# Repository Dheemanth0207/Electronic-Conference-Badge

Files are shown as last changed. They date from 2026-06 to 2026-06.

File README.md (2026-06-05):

# Electronic Conference Badge

## Project Overview

This project investigates the design and development of a smart, energy-efficient electronic conference badge intended to replace traditional printed name tags used at events and meetings. The system is built around a compact microcontroller board, which controls a 3.52-inch e-paper display capable of showing attendee names, designations, or other event-specific content. Unlike conventional displays, e-paper offers excellent readability in various lighting conditions, including bright sunlight, while consuming very little power, making it ideal for multi-day usage on a single charge. 

The badge is designed to be interactive and easily programmable, featuring a set of physical buttons for input and wireless communication that allow it to connect with other badges or systems for capabilities such as contact exchange, activity tracking, or peer-to-peer messaging. A SD card reader also provides the flexibility to update the badge content without relying on an internet connection, making it useful in both connected and standalone scenarios

To reliably support all of these features, the hardware integrates a combination of power management circuits to ensure stable operation across different use cases. These include a voltage regulator and boost converter to provide the necessary voltages for the logic components and display. The board is powered by a 3.7V rechargeable battery and is charged or programmed via a USB Type-C connector. 

All design work, including schematic creation and PCB layout, was completed using the open-source KiCAD 9 design tool, ensuring that the board is optimized for surface-mount manufacturing. By combining low-power electronics, open-source design tools, and a thoughtful user interface, this badge system offers a modern, reusable, and sustainable alternative to traditional paper-based identification at events. 

## Hardware Preview

### Schematic
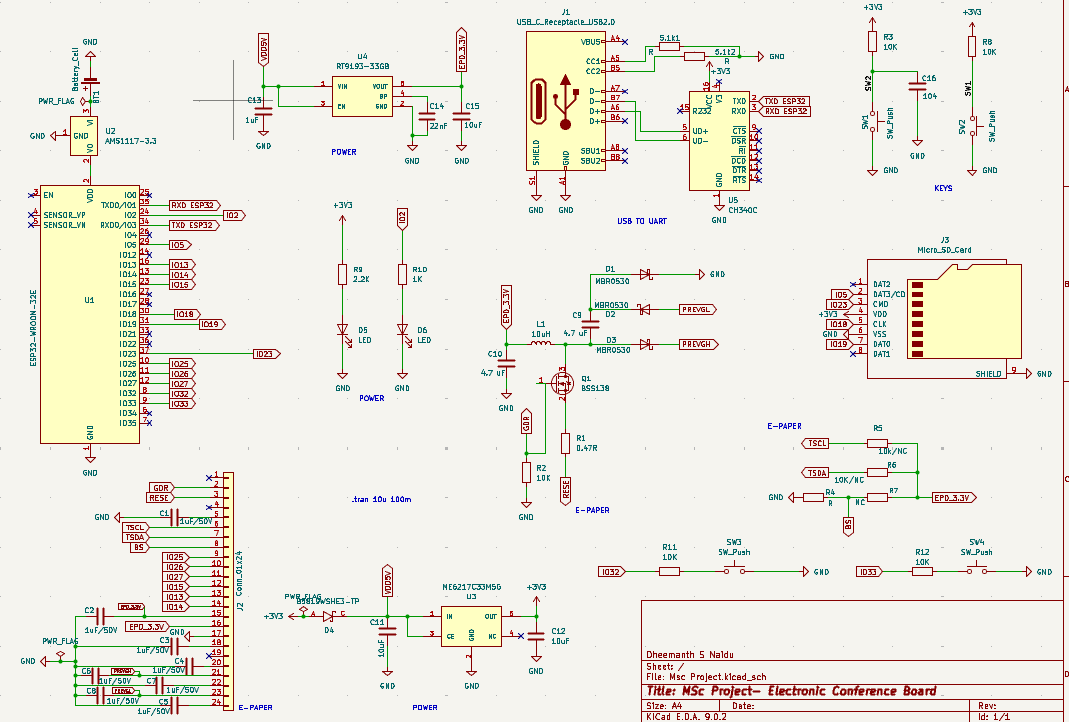
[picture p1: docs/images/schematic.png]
Schematic


### PCB Layout
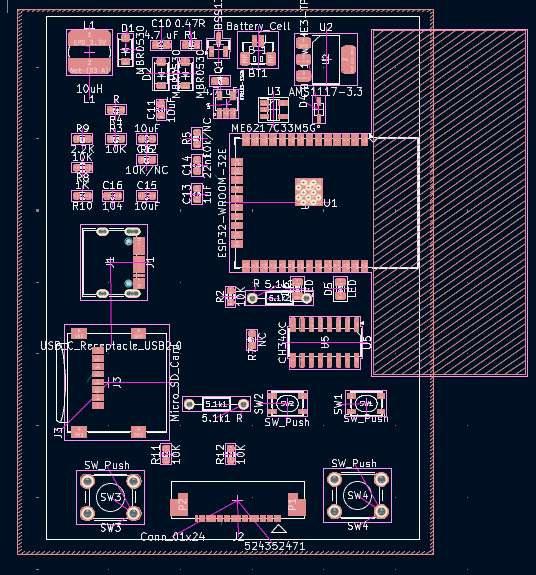
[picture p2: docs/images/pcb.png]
PCB Layout


### 3D Render
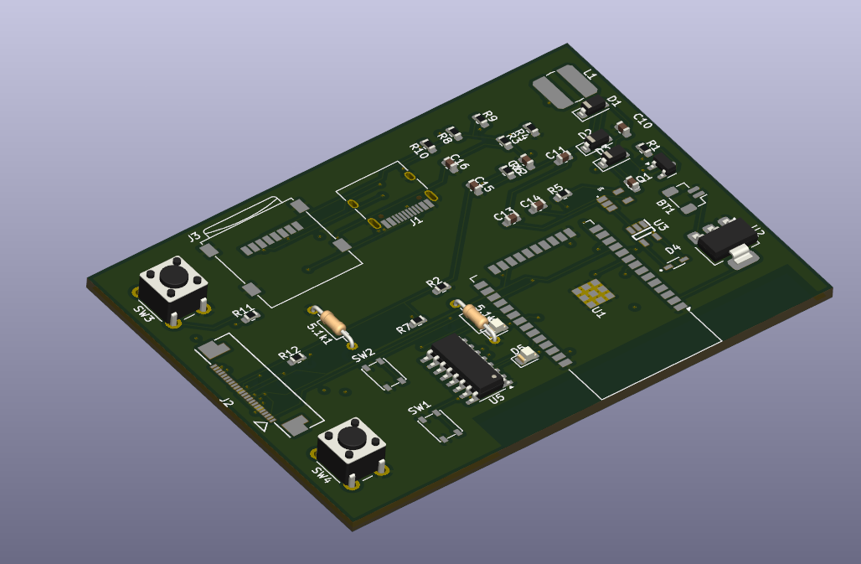
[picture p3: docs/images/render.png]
3D Render


## 🛠️ Requirements

To view, edit, or manufacture this project, the following software is required:

* **KiCad 9.0 or later**
* A computer running Windows, Linux, or macOS
* Optional: Gerber viewer for manufacturing file verification

## 📥 Installation

### 1. Install KiCad

Download and install the latest version of KiCad from the official website:

https://www.kicad.org/download/

Verify that KiCad is correctly installed by launching the application and opening the Project Manager.

### 2. Clone the Repository

```bash
git clone https://github.com/<your-username>/<repository-name>.git
cd <repository-name>
```

Alternatively, download the project as a ZIP file and extract it to your desired location.

### 3. Open the Project

1. Launch **KiCad 9**.
2. Select **File → Open Project**.
3. Navigate to the project directory.
4. Open the `.kicad_pro` file.

The project schematic, PCB layout, symbols, footprints, and manufacturing files will now be available through the KiCad Project Manager.

## 📂 Project Structure

```text
Project/
│
├── Hardware/
│   ├── Schematics/
│   ├── PCB/
│   ├── Libraries/
│   └── Manufacturing/
│
├── Documentation/
│   ├── Images/
│   └── Datasheets/
│
└── README.md
```

## 🔧 Editing the Design

### Schematic

1. Open the project in KiCad.
2. Click **Schematic Editor**.
3. Modify components, connections, or annotations as required.
4. Run **Electrical Rules Check (ERC)** before saving changes.

### PCB Layout

1. Open **PCB Editor**.
2. Update the PCB from the schematic if changes have been made.
3. Verify component placement and routing.
4. Run **Design Rules Check (DRC)** to identify any layout issues.

## 📤 Generating Manufacturing Files

To generate fabrication files:

1. Open the PCB Editor.
2. Select **File → Fabrication Outputs → Gerbers**.
3. Generate Gerber files for all required layers.
4. Generate drill files using **Generate Drill Files**.
5. Review the outputs using a Gerber viewer before sending them to a PCB manufacturer.

## 🔋 Hardware Features

* 3.52-inch E-Paper Display
* Low-power microcontroller platform
* Wireless communication capability
* Physical navigation buttons
* MicroSD card support
* USB Type-C charging and programming
* Rechargeable 3.7 V Li-ion battery support
* Integrated voltage regulation and boost conversion circuitry
* Surface-mount optimized PCB design

## 🤝 Contributing

Contributions, suggestions, and improvements are welcome. Please fork the repository, create a feature branch, and submit a pull request describing your changes.

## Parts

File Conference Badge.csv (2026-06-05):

Id | Designator | Footprint | Quantity | Designation | Supplier and ref
1 | R7 | R_0603_1608Metric | 1 | NC
2 | 5.1k1,5.1k2 | R_Axial_DIN0204_L3.6mm_D1.6mm_P7.62mm_Horizontal | 2 | R
3 | R11,R8,R2,R12,R3 | R_0603_1608Metric | 5 | 10K
4 | C8,C1,C2,C3,C4,C7,C5,C6 | C_0603_1608Metric | 8 | 1uF/50V
5 | C12,C11,C15 | C_0603_1608Metric | 3 | 10uF
6 | D2,D3,D1 | D_SOD-123 | 3 | MBR0530
7 | R4 | R_0603_1608Metric | 1 | R
8 | C14 | C_0603_1608Metric | 1 | 22nF
9 | R10 | R_0603_1608Metric | 1 | 1K
10 | J3 | microSD_HC_Wuerth_693072010801 | 1 | Micro_SD_Card
11 | SW3,SW4 | SW_PUSH_6mm | 2 | SW_Push
12 | L1 | L_Bourns_SDR0604 | 1 | 10uH
13 | BT1 | JST_SH_BM02B-SRSS-TB_1x02-1MP_P1.00mm_Vertical | 1 | Battery_Cell
14 | C16 | C_0603_1608Metric | 1 | 104
15 | C10,C9 | C_0603_1608Metric | 2 | 4.7 uF
16 | J2 | CON_524352471_MOL | 1 | Conn_01x24
17 | Q1 | SOT-23 | 1 | BSS138
18 | U4 | SOT94P279X129-5N | 1 | RT9193-33GB
19 | R1 | R_0603_1608Metric | 1 | 0.47R
20 | D5,D6 | LED_0805_2012Metric | 2 | LED
21 | C13 | C_0603_1608Metric | 1 | 1uF
22 | U2 | SOT-223-3_TabPin2 | 1 | AMS1117-3.3
23 | D4 | SOD2512X115N | 1 | B5819WSHE3-TP
24 | U3 | SOT23-5 | 1 | ME6217C33M5G
25 | J1 | USB_C_Receptacle_HRO_TYPE-C-31-M-12 | 1 | USB_C_Receptacle_USB2.0
26 | SW2,SW1 | SW_SPST_PTS810 | 2 | SW_Push
27 | R6 | R_0603_1608Metric | 1 | 10K/NC
28 | U5 | SOIC-16_3.9x9.9mm_P1.27mm | 1 | CH340C
29 | R5 | R_0603_1608Metric | 1 | 10k/NC
30 | U1 | ESP32-WROOM-32D | 1 | ESP32-WROOM-32E
31 | R9 | R_0603_1608Metric | 1 | 2.2K

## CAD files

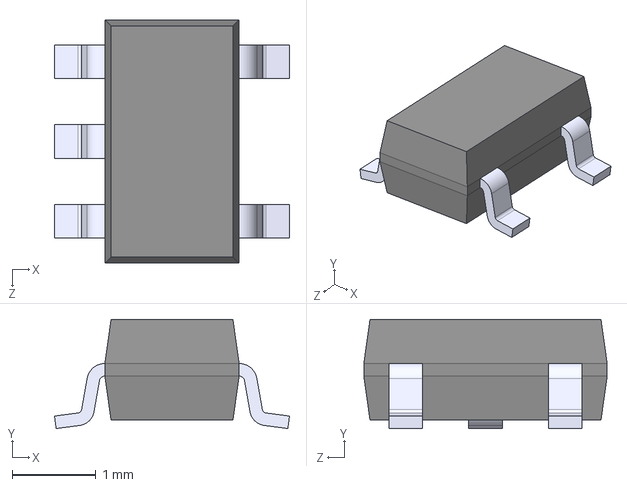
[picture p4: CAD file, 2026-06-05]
ME6217C33M5G/ME6217C33M5G.step
2.80 x 1.30 x 2.90 mm

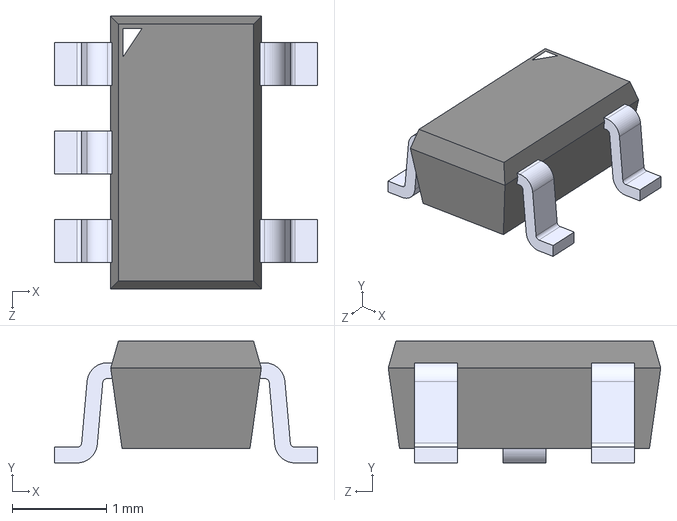
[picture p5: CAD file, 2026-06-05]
RT9193-33GB/RT9193-33GB.step
2.79 x 1.30 x 2.90 mm

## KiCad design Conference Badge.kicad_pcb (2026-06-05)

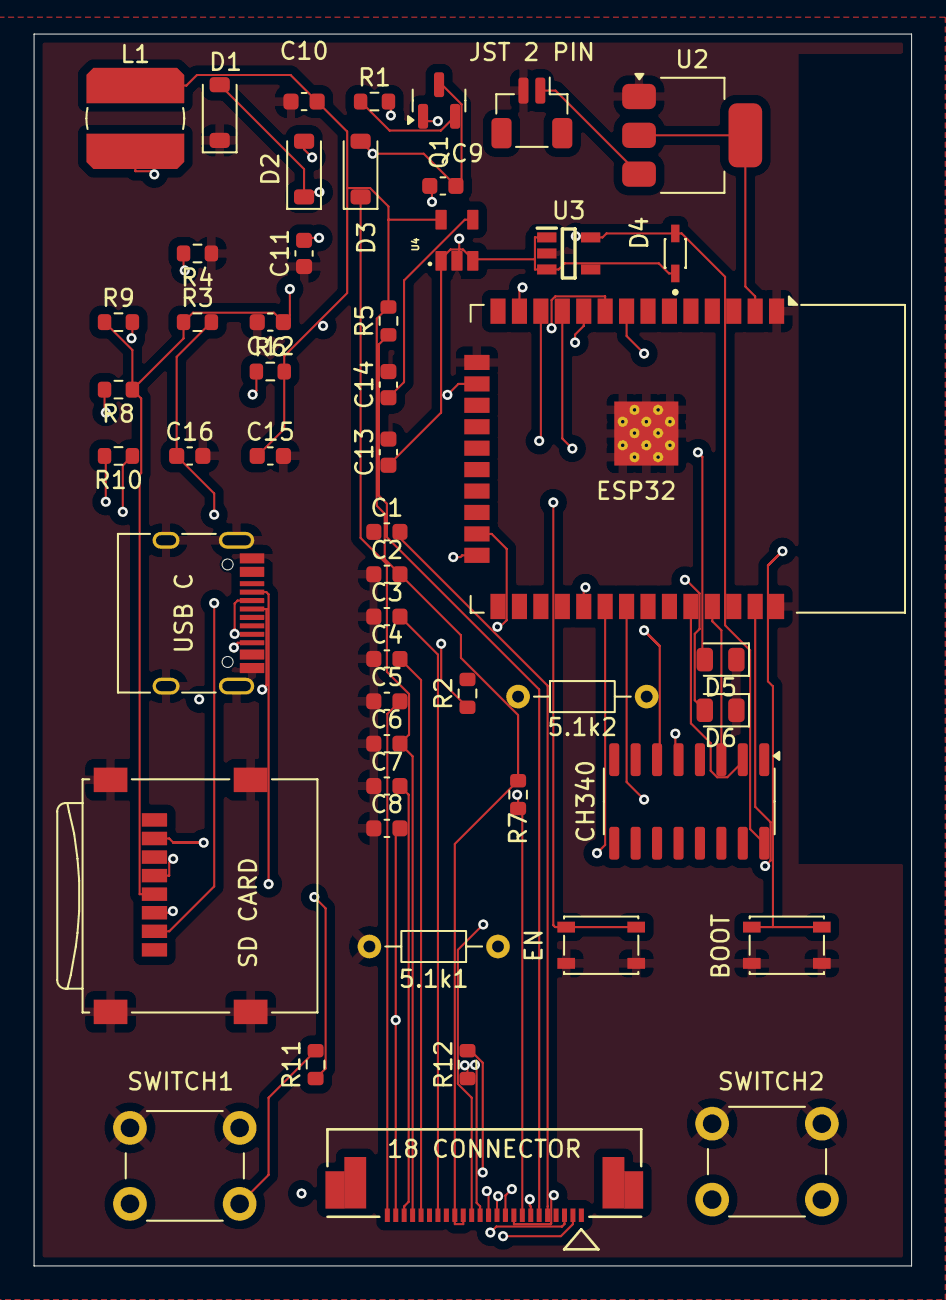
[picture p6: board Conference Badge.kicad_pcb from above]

Board: 4 copper layers, 52.0 x 73.0 mm, 51 parts (0 on the bottom side), 47 nets.

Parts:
5.1k1, 5.1k2: R; R_Axial_DIN0204_L3.6mm_D1.6mm_P7.62mm_Horizontal
18 CONNECTOR : Conn_01x24; CON_524352471_MOL
BOOT: BOOT; SW_SPST_PTS810
C1, C2, C3, C4, C5, C6, C7, C8: 1uF/50V; C_0603_1608Metric
C9, C10: 4.7 uF; C_0603_1608Metric
C11, C12, C15: 10uF; C_0603_1608Metric
C13: 1uF; C_0603_1608Metric
C14: 22nF; C_0603_1608Metric
C16: 104; C_0603_1608Metric
CH340: CH340C; SOIC-16_3.9x9.9mm_P1.27mm
D1, D2, D3: MBR0530; D_SOD-123
D4: B5819WSHE3-TP; SOD2512X115N
D5, D6: LED; LED_0805_2012Metric
EN: EN; SW_SPST_PTS810
ESP32: ESP32-WROOM-32E; ESP32-WROOM-32D
JST 2 PIN: Battery_Cell; JST_SH_BM02B-SRSS-TB_1x02-1MP_P1.00mm_Vertical
L1: 10uH; L_Bourns_SDR0604
Q1: BSS138; SOT-23
R1: 0.47R; R_0603_1608Metric
R2, R3, R8, R11, R12: 10K; R_0603_1608Metric
R4: R; R_0603_1608Metric
R5: 10k/NC; R_0603_1608Metric
R6: 10K/NC; R_0603_1608Metric
R7: NC; R_0603_1608Metric
R9: 2.2K; R_0603_1608Metric
R10: 1K; R_0603_1608Metric
SD CARD: Micro_SD_Card; microSD_HC_Wuerth_693072010801
SWITCH1, SWITCH2: SW_Push; SW_PUSH_6mm
U2: AMS1117-3.3; SOT-223-3_TabPin2
U3: ME6217C33M5G; SOT23-5
U4: RT9193-33GB; SOT94P279X129-5N
USB C : USB_C_Receptacle_USB2.0; USB_C_Receptacle_HRO_TYPE-C-31-M-12

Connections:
+3V3: C12.1, CH340.16 (VCC), D4.A, R3.1, R8.1, R9.1, SD CARD.4 (VDD), U3.5 (OUT)
/SW1: EN.1, R8.2
/SW2: BOOT.1, C16.1, R3.2
BS: 18 CONNECTOR.8, R4.2, R7.1
EPD_3.3V: 18 CONNECTOR.15, 18 CONNECTOR.16, C2.2, C10.1, C15.1, L1.1, R5.2, R6.2, R7.2, U4.5 (VOUT)
GDR: 18 CONNECTOR.2, Q1.1 (G), R2.1
GND: 5.1k1.2, 5.1k2.2, 18 CONNECTOR.17, BOOT.2, C1.1, C2.1, C3.1, C4.1, C5.1, C6.1, C7.1, C8.1, C10.2, C11.1, C12.2, C13.2, C14.2, C15.2, C16.2, CH340.1 (GND), D1.1 (K), D5.1 (K), D6.1 (K), EN.2, ESP32.1 (GND), ESP32.15 (GND), ESP32.38 (GND), ESP32.39 (GND), JST 2 PIN.2 (-), R2.2, R4.1, SD CARD.6 (VSS), SD CARD.9 (SHIELD), SWITCH1.2, SWITCH2.2, U2.1 (GND), U3.2 (GND), U4.2 (GND), USB C.A1 (GND), USB C.A12 (GND), USB C.B1 (GND), USB C.B12 (GND), USB C.S1 (SHIELD)
IO2: ESP32.24 (IO2), R10.1
IO5: ESP32.29 (IO5), SD CARD.2 (DAT3/CD)
IO13: 18 CONNECTOR.13, ESP32.16 (IO13)
IO14: 18 CONNECTOR.14, ESP32.13 (IO14)
IO15: 18 CONNECTOR.12, ESP32.23 (IO15)
IO18: ESP32.30 (IO18), SD CARD.5 (CLK)
IO19: ESP32.31 (IO19), SD CARD.7 (DAT0)
IO23: ESP32.37 (IO23), SD CARD.3 (CMD)
IO25: 18 CONNECTOR.9, ESP32.10 (IO25)
IO26: 18 CONNECTOR.10, ESP32.11 (IO26)
IO27: 18 CONNECTOR.11, ESP32.12 (IO27)
IO32: ESP32.8 (IO32), R11.1
IO33: ESP32.9 (IO33), R12.1
unnamed: JST 2 PIN.1 (+), U2.3 (VI)
unnamed: C9.1, D1.2 (A), D2.1 (K)
unnamed: C9.2, D3.2 (A), L1.2, Q1.3 (D)
unnamed: D5.2 (A), R9.2
unnamed: D6.2 (A), R10.2
unnamed: 5.1k1.1, USB C.A5 (CC1)
unnamed: 5.1k2.1, USB C.B5 (CC2)
unnamed: 18 CONNECTOR.5, C1.2
unnamed: 18 CONNECTOR.18, C3.2
unnamed: 18 CONNECTOR.20, C4.2
unnamed: 18 CONNECTOR.22, C7.2
unnamed: 18 CONNECTOR.24, C5.2
unnamed: Q1.2 (S), R1.1
unnamed: R11.2, SWITCH1.1
unnamed: R12.2, SWITCH2.1
unnamed: ESP32.2 (VDD), U2.2 (VO)
unnamed: C14.1, U4.4 (BP)
unnamed: CH340.5 (UD+), USB C.A6 (D+)
unnamed: CH340.6 (UD-), USB C.B7 (D-)
PREVGH: 18 CONNECTOR.21, C6.2, D3.1 (K)
PREVGL: 18 CONNECTOR.23, C8.2, D2.2 (A)
RESE: 18 CONNECTOR.3, R1.2
RXD ESP32: CH340.3 (RXD), ESP32.35 (TXD0/IO1)
TSCL: 18 CONNECTOR.6, R5.1
TSDA: 18 CONNECTOR.7, R6.1
TXD ESP32: CH340.2 (TXD), ESP32.34 (RXD0/IO3)
VDD5V: C11.2, C13.1, D4.C, U3.1 (IN), U3.3 (CE), U4.1 (VIN), U4.3 (EN)

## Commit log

2026-06-05 Enhance README with detailed project description
    Expanded project description to include details about the microcontroller, e-paper display, interactivity, and power management features.
2026-06-05 Add ConferenceBadge.kicad_sym file
2026-06-05 Rename Msc Project.csv to Conference Badge.csv
    [Conference Badge.csv]
2026-06-05 Rename Msc Project.kicad_dru to Conference Badge.kicad_dru
2026-06-05 Add Conference Badge PCB file
    [Conference Badge.kicad_pcb]
2026-06-05 Rename Msc Project.kicad_sch-bak to Conference Badge.kicad_sch-bak
2026-06-05 Rename Msc Project.kicad_prl to Conference Badge.kicad_prl
2026-06-05 Rename Msc Project.kicad_pro to Conference Badge.kicad_pro
2026-06-05 Rename Msc Project.kicad_sch to Conference Badge.kicad_sch
    [Conference Badge.kicad_sch]
2026-06-05 Rename Msc Project.kicad_sym to Conference Badge.kicad_sym
